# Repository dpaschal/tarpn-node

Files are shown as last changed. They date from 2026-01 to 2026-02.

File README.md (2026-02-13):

> **Important:** This isn't the documentation or code that Tadd KA2DEW supervises. That code is at https://tarpn.net/
> Technical support is available for the tarpn.net code and documentation at [tarpn@groups.io](https://groups.io/g/tarpn).

# TARPN Node

<p align="center">
  <a href="https://buymeacoffee.com/dpaschal">
    
  </a>
</p>

<p align="center">
  <b>☕ Buy me Claude Code credits or support a project! ☕</b>
</p>
<p align="center">
  <i>Every donation keeps the code flowing — these tools are built with your support.</i>
</p>

<p align="center">
  <a href="https://buymeacoffee.com/dpaschal">
    Buy Me A Coffee
  </a>
</p>

---

A modern, centralized repository for building TARPN (Terrestrial Amateur Radio Packet Network) nodes.




> **Note:** Documentation is actively being developed. Core scripts and STL files are ready for use. Some documentation pages contain placeholder content marked "Documentation In Progress".

## What is TARPN?

TARPN is an off-grid amateur radio social network that operates entirely over ham radio infrastructure - no internet required. It enables multi-state email, live chat, and social interaction using dedicated point-to-point VHF/UHF radio links.

**Key Features:**
- 100% ham operator controlled infrastructure
- Grid-independent (survives internet/cellular outages)
- Low cost (~$500-650 for complete dual-port node)
- Educational (teaches networking, radio, and digital communications)

## Quick Start

### Hardware Required

| Component | Qty | Est. Cost |
|---|-----|---|
| Raspberry Pi 4B (1GB+) | 1 | $45 |
| 16GB micro SD (Class 10) | 1 | $8 |
| NinoTNC N9600A | 2 | $80-140 |
| VHF/UHF Radio (surplus) | 2 | $100 |
| 13.8V Power Supply | 1 | $50-100 |
| Antennas | 2 | $140 |
| 3D Printed Enclosure | 1 | $20 |

See [hardware/bom/](hardware/bom/) for complete bill of materials with links.

### Software Installation

```bash
# Download and run the installer
curl -sSL https://raw.githubusercontent.com/dpaschal/tarpn-node/main/scripts/install.sh | bash
```

Or clone and run locally:

```bash
git clone https://github.com/dpaschal/tarpn-node.git
cd tarpn-node
./scripts/install.sh
```

### 3D Printed Enclosure

STL files for the single-wide nodebox are in [hardware/enclosure/stl/](hardware/enclosure/stl/).

**Print Settings:**
- Material: PLA or PETG
- Layer Height: 0.2mm
- Infill: 20-30%
- Supports: As needed per part

See [docs/hardware/enclosure/](docs/hardware/enclosure/) for assembly instructions.

## Documentation

Full documentation available at: **https://dpaschal.github.io/tarpn-node**

- [Hardware Build Guide](docs/hardware/)
- [Software Installation](docs/software/installation.md)
- [Configuration Guide](docs/software/configuration.md)
- [Network Setup](docs/network/)
- [Troubleshooting](docs/software/troubleshooting.md)

## Repository Structure

```
tarpn-node/
├── docs/               # MkDocs documentation
├── hardware/
│   ├── enclosure/stl/  # 3D print files
│   ├── wiring/         # Wiring diagrams
│   └── bom/            # Bill of materials
├── scripts/            # Installation and management scripts
├── config/             # Configuration templates
├── image/              # SD card image build system
└── tests/              # Automated tests
```

## TARPN Commands

After installation, use the `tarpn` command:

```bash
tarpn                  # Show status
tarpn config           # Configure node
tarpn service start    # Start background service
tarpn home start       # Start web interface
tarpn update           # Update TARPN software
tarpn backup           # Backup configuration
tarpn test             # Test node operation
```

## Community

- **NCPACKET (NC Area):** [ncpacket@groups.io](https://groups.io/g/ncpacket)
- **TARPN Technical:** [tarpn@groups.io](https://groups.io/g/tarpn)
- **Issues:** [GitHub Issues](https://github.com/dpaschal/tarpn-node/issues)

## Credits

- **TARPN Project:** Tadd Torborg (KA2DEW) - [tarpn.net](https://tarpn.net)
- **LinBPQ:** John Wiseman (G8BPQ) - [g8bpq/LinBPQ](https://github.com/g8bpq/LinBPQ)
- **NinoTNC:** Nino Carrillo (KK4HEJ)
- **Enclosure Design:** TARPN Community

## License

MIT License - See [LICENSE](LICENSE) for details.

---

*This repository modernizes and centralizes the TARPN node build process, previously scattered across multiple websites and scripts.*

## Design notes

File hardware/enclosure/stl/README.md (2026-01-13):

# Single-Wide Nodebox STL Files

3D printable enclosure for a TARPN node with dual radios and dual NinoTNCs.

**Design:** Tadd Torborg (KA2DEW)
**Version:** 2025-09-13

## Print Quantities

Based on the official assembly instructions, print the following quantities:

### Structural Components

| Qty | File | Description |
|-----|---|---|
| 16 | `beam-2025apr25-1.stl` | Horizontal beams |
| 16 | `corner-tower-T2025may01-1.stl` | Corner posts |
| 4 | `foot-jul15-1.stl` | Rubber foot mounts |

### Bottom Panels

| Qty | File | Description |
|-----|---|---|
| 4 | `bottom-panel-stephen-2024sep05-1.stl` | Bottom panels |
| 4 | `bottom-panel-key.stl` | Bottom panel locks |

### Side Panels

| Qty | File | Description |
|-----|---|---|
| 11 | `side-panel-jul09-1.stl` | Side panels |
| 1 | `right-half-with-vent-holes-25feb25-7.stl` | Vented right panel |
| 1 | `hinged-200mm-panel-2025may23-1.stl` | Hinged access panel |

### Roof Components

| Qty | File | Description |
|-----|---|---|
| 4 | `roof-corner-25jan03-1.stl` | Roof corner pieces |
| 4 | `roof-edge-beam-25jan04-2.stl` | Roof edge beams |
| 4 | `roof-quadrant-25jan05-1.stl` | Roof quadrant panels |

### NinoTNC Mounting

| Qty | File | Description |
|-----|---|---|
| 4 | `ninotnc-panel-jul15-2.stl` | TNC front panel |
| 4 | `ninotnc-tray-handle-2025apr28-2.stl` | TNC tray handle |
| 4 | `ninotnc-vertical-a4-tray-2025apr30-1.stl` | Vertical TNC tray |

### Power & Control

| Qty | File | Description |
|-----|---|---|
| 1 | `control-panel-25may27-2.stl` | Main control panel |
| 1 | `power-supply-panel-25feb01-1.stl` | Power supply panel |
| 1 | `power-supply-support-2025mar21-3.stl` | Power supply bracket |
| 1 | `fuse-holder-2025apr12-2.stl` | Fuse holder mount |
| 1 | `battery-jan02-1.stl` | Battery holder |

### I/O Cutouts

| Qty | File | Description |
|-----|---|---|
| 1 | `ethernet-socket-july30-1.stl` | Ethernet port cutout |
| 1 | `hdmi-and-usb-big-socket-hole-2025apr03-1.stl` | HDMI/USB cutout |
| 4 | `coax-hole-53mm-25jan02-1.stl` | Coax feedthrough (53mm) |
| 6 | `vented-53mm-jul16-1.stl` | Vented 53mm hole |

### Radio Mounts (Choose Based on Your Radios)

| Qty | File | Description |
|-----|---|---|
| 4 | `tait-radio-25jan03-1.stl` | Tait radio mount |
| as needed | `vertex_Mount_20250421-1.stl` | Vertex radio mount |
| as needed | `yeasu-ftm3100r-2025apr12-1.stl` | Yaesu FTM-3100R mount |

### Tools

| Qty | File | Description |
|-----|---|---|
| 1 | `nut-placer-in-beam-2025mar16-1.stl` | Tool for inserting nuts into beams |

### Multi-Part Files

| File | Description |
|---|---|
| `corners_and_beams.3mf` | Combined print of corners and beams |

## Print Settings

**Recommended:**

| Setting | Value |
|---|---|
| Material | PLA or PETG |
| Layer Height | 0.2mm |
| Infill | 20-30% |
| Walls | 3 perimeters |
| Top/Bottom | 4 layers |

**Per-Part Notes:**

- **Structural parts** (corners, beams): 30% infill for strength
- **Panels**: 20% infill is sufficient
- **Radio mounts**: PETG preferred for heat resistance near radios

## Hardware Required

- M3 x 10mm screws (qty: ~50)
- M3 x 35mm screws (qty: 4)
- M3 square nuts (qty: ~60)
- 2.5mm hex driver

## Total Print Summary

| Category | Part Count | Est. Print Time |
|---|---|---|
| Structural | 36 parts | ~20 hours |
| Panels | 16 parts | ~15 hours |
| Roof | 12 parts | ~8 hours |
| NinoTNC | 12 parts | ~6 hours |
| Power/Control | 5 parts | ~4 hours |
| I/O | 12 parts | ~3 hours |
| Radio Mounts | 4 parts | ~2 hours |
| **Total** | **~97 parts** | **~58 hours** |

*Print times estimated at 60mm/s with 0.2mm layer height*

## Assembly

See [Assembly Guide](../../../docs/hardware/enclosure/assembly.md) for detailed step-by-step instructions with photos.

## Credits

Enclosure designed by Tadd Torborg (KA2DEW) for the TARPN project.

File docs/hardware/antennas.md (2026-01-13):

# Antennas

!!! note "Documentation In Progress"
    This page is under construction. Check back soon!

## Antenna Types

| Type | Gain | Use Case |
|---|---|---|
| J-Pole | 0 dBd | Omnidirectional, local |
| Yagi | 6-12 dBd | Directional, long links |
| Collinear | 3-6 dBd | Omnidirectional, range |

## Recommendations

- **Point-to-point links**: Yagi antennas aimed at neighbor
- **Local coverage**: Vertical omnidirectional
- **Separate antennas** for each radio port

## Feedline

- Use quality coax (LMR-400 or equivalent)
- Keep runs as short as practical
- Use proper weatherproofing outdoors

## Resources

- [ARRL Antenna Book](http://www.arrl.org/antenna-book)

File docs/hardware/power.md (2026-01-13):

# Power Supply

!!! note "Documentation In Progress"
    This page is under construction. Check back soon!

## Requirements

| Component | Voltage | Current |
|---|---|---|
| Raspberry Pi | 5V | 3A |
| Radios (each) | 13.8V | 5-10A TX |
| NinoTNC | 5V (USB) | 100mA |

## Recommended Setup

- **Main supply**: 13.8V DC, 20-30A switching supply
- **Pi power**: USB-C 5V 3A adapter, or 12V-to-5V converter
- **Backup**: Optional 12V battery for Pi continuity

## Fusing

- Fuse each radio individually
- Main supply fuse at distribution point
- See [Fuse Holder STL](enclosure/stl/README.md)

## Resources

- [TARPN Power Guide](https://tarpn.net/t/builder/builders_power.html)

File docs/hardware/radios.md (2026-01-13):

# Radio Setup

!!! note "Documentation In Progress"
    This page is under construction. Check back soon!

## Recommended Radios

| Radio | Band | Notes |
|---|---|---|
| Tait TM8100/8200 | VHF/UHF | Excellent, surplus available |
| Motorola CDM1250 | VHF/UHF | Common, reliable |
| Yaesu FTM-3100R | 2m | New, affordable |
| Vertex VX-2200 | VHF/UHF | Commercial grade |

## Requirements

- FM transceiver (VHF or UHF)
- 9600 baud capable (for high-speed links)
- Flat audio response preferred
- 25-50W output typical

## Wiring

Connect radio to NinoTNC via audio cable:

- TX Audio (TNC to radio mic input)
- RX Audio (radio speaker to TNC)
- PTT (active low)
- Ground

## Resources

- [NinoTNC Connections](ninotnc.md#connections)
- [TARPN Radio Guide](https://tarpn.net/t/builder/builders_radio_selection.html)

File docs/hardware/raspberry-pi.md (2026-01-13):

# Raspberry Pi Setup

!!! note "Documentation In Progress"
    This page is under construction. Check back soon!

## Recommended Models

| Model | RAM | Status |
|---|-----|---|
| Pi 4B | 2GB+ | Recommended |
| Pi 3B+ | 1GB | Supported |
| Pi Zero 2 W | 512MB | Supported (limited) |

## OS Requirements

- Raspberry Pi OS (Bullseye or Bookworm)
- 32-bit or 64-bit supported

## Initial Setup

1. Flash Raspberry Pi OS to SD card
2. Enable SSH
3. Boot and connect to network
4. Run TARPN installer:

```bash
curl -sSL https://raw.githubusercontent.com/dpaschal/tarpn-node/main/scripts/install.sh | bash
```

## Resources

- [Raspberry Pi Imager](https://www.raspberrypi.com/software/)
- [TARPN Installation Guide](../software/installation.md)

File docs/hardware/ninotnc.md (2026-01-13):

# NinoTNC N9600A

The NinoTNC N9600A is the recommended TNC (Terminal Node Controller) for TARPN nodes. Designed by Nino Carrillo (KK4HEJ), it's a multi-mode USB KISS TNC supporting amateur packet radio from 300 to 19,200 baud.

**Designer:** Nino Carrillo, KK4HEJ

**In Service:** Over 2,800 boards shipped, 120+ units in NC Packet network

## Specifications

| Specification | Value |
|---|---|
| Interface | USB serial at 57,600 baud |
| Protocol | KISS |
| Layer 2 | AX.25, IL2P, IL2P+CRC |
| Baud Rates | 300, 1200, 2400, 3600, 4800, 9600, 19200 |
| RX Input | 0.3V - 3V peak-to-peak |
| Connectors | 9-pin DE9 (kit) or 6-pin mini-DIN (SMT) |
| Power | USB powered (5V) |

## Operating Modes

The NinoTNC supports 16 modes via the MODE switch, covering three protocol families:

### Legacy AX.25 Modes

| Mode | Baud | Modulation | Use Case |
|---|---|---|---|
| 300 AFSK | 300 | 1600/1800 Hz tones | SSB HF packet |
| 1200 AFSK | 1200 | Bell 202 | FM packet, APRS |
| 9600 GFSK | 9600 | G3RUH | High-speed FM |

### IL2P FEC Modes (Recommended)

| Mode | Baud | Modulation | Use Case |
|---|---|---|---|
| 300-600 BPSK/QPSK | 300-600 | PSK, 500 Hz BW | SSB HF |
| 1200-2400 BPSK/QPSK | 1200-2400 | PSK, 2400 Hz BW | FM/SSB |
| 3600 QPSK | 3600 | QPSK | FM (narrow filters OK) |
| 4800-19200 GFSK/C4FSK | 4800-19200 | G3RUH/FSK | Data port |

### Performance

| Mode | Throughput | Notes |
|---|---|---|
| 9600 G3RUH | 125 bytes/sec | With fast-switching radio |
| 2400 DPSK | Good | Works with mic-audio radios |
| 4800 GFSK | Good | For radios that can't do 9600 |

!!! info "IL2P Advantage"
    IL2P provides approximately **4dB improvement** in signal-to-noise ratio compared to AX.25.

## IL2P Protocol

The NinoTNC supports IL2P (Improved Layer 2 Protocol), which provides:

- **Forward Error Correction (FEC)** - Approximately 4dB improvement over standard AX.25
- **Better noise immunity** - More reliable links in marginal conditions
- **Backward compatible framing** - Works with existing AX.25 infrastructure
- **Designed by KK4HEJ** - Specifically for amateur radio packet

!!! tip "Use IL2P"
    IL2P is strongly recommended for TARPN links. It provides significant performance improvement with no hardware changes.

## Connections

### Audio Connections

The NinoTNC uses a 6-pin mini-DIN connector for radio audio:

| Pin | Signal | Description |
|-----|---|---|
| 1 | TX Audio | Transmit audio to radio |
| 2 | Ground | Audio ground |
| 3 | PTT | Push-to-talk (ground to transmit) |
| 4 | RX Audio | Receive audio from radio |
| 5 | Ground | Audio ground |
| 6 | +5V | Optional power output |

### USB Connection

Connect to any USB port on the Raspberry Pi. The NinoTNC appears as `/dev/ttyUSB0`, `/dev/ttyUSB1`, etc.

## Configuration

### Checking USB Connection

```bash
# List USB devices
tarpn usb

# Or manually
ls -la /dev/ttyUSB*
```

### Identifying TNCs

```bash
# Query TNC version
tarpn identify
```

### LinBPQ Port Configuration

In `bpq32.cfg`, configure a NinoTNC port:

```
PORT
  PORTNUM=1
  ID=VHF 9600 IL2P
  TYPE=ASYNC
  PROTOCOL=KISS
  COMPORT=/dev/ttyUSB0
  SPEED=57600
  CHANNEL=A
  PERSIST=128
  SLOTTIME=100
  TXDELAY=200
  TXTAIL=50
  QUALITY=203
  MAXFRAME=4
  FRACK=5000
  RESPTIME=1500
  RETRIES=5
  PACLEN=236
ENDPORT
```

## LED Indicators

The NinoTNC has five status LEDs:

| LED | Color | Designator | Function |
|-----|---|---|---|
| CRC | Red | D5 | CRC errors, high RX volume warning |
| Queue | Blue | D6 | TX queue has data waiting |
| RX | Green | D4 | Successful packet received (2 sec) |
| DCD | Yellow | D3 | Data Carrier Detect active |
| PTT | Red | D1 | Transmitting |

**Startup Sequence:** Four-LED sweep pattern indicates reset or mode change.

**CRC LED Tuning:** Adjust receive volume until CRC LED flickers, then reduce until it stops - this is optimal receive level.

## Firmware Updates

### Check Current Version

```bash
tarpn identify
```

### Flash New Firmware

1. Download firmware from TARPN website
2. Place `.hex` file in `/usr/local/etc/ninotnc/versions/`
3. Run firmware flash utility:

```bash
tarpn flash
```

Or manually with Python:

```bash
python3 flashtnc.py /dev/ttyUSB0 firmware.hex
```

## Troubleshooting

### TNC Not Detected

1. Check USB cable connection
2. Verify with `dmesg | tail` after plugging in
3. Check permissions: `ls -la /dev/ttyUSB*`
4. Add user to dialout group: `sudo usermod -a -G dialout pi`

### No TX/RX Activity

1. Verify audio cable connections
2. Check radio squelch settings
3. Verify PTT line is working
4. Check baud rate matches neighbor

### Poor Link Quality

1. Try adjusting TX delay (`TXDELAY` in config)
2. Verify audio levels (not too hot or too quiet)
3. Check antenna and feedline
4. Consider switching to IL2P if using AX.25

## Hardware Versions

| Version | Period | Status |
|---|---|---|
| A0, A1 | Aug 2018 - Jan 2020 | Unsupported |
| A2 | Jan 2020 - Aug 2020 | Supported (200 units) |
| A3 | May 2020 - Nov 2020 | Supported (800 units) |
| A4 | Dec 2020 - present | Current (thousands) |
| A4r3 | Feb 2024+ | Current production |

The A4r3 revision was created when the original MOSFET (Q1) was discontinued.

## Purchasing

### Kit Version (DIY)

- **PCB + CPU from ETSY:** ~$12 USD
- **Components from Mouser:** ~$30 USD
- **Total:** Under $40

### Assembled Units

- **RPC-Electronics:** ~$70 + shipping (SMT version)
- **HamServe.UK:** PCB, kits, or assembled (international)
- **OARC.UK via Tindie:** PCB + CPU (EU)

## Firmware

| CPU Type | Firmware Version |
|---|---|
| dsPIC33EP256 | v3.44 (current) |
| dsPIC33EP512 | v4.44 (current) |

!!! warning "Firmware Compatibility"
    Use v3.X firmware for EP256GP CPU, v4.X for EP512GP CPU. Do not mix versions.

## KISS Parameters for LinBPQ

```
SPEED=57600
PROTOCOL=KISS
PERSIST=225
SLOTTIME=20
FRACK=6000    ; 1200 baud
FRACK=2000    ; 9600 baud
PACLEN=236    ; 1200 baud
PACLEN=202    ; 9600 baud
```

## Resources

- [Operator's Manual](https://tarpn.net/t/nino-tnc/n9600a/n9600a_operation.html)
- [Info & Ordering](https://tarpn.net/t/nino-tnc/n9600a/n9600a_info.html)
- [Assembly Instructions](https://tarpn.net/t/nino-tnc/n9600a/n9600a3/n9600a3-assembly.html)
- [Firmware Updater (GitHub)](https://github.com/ninocarrillo/flashtnc)
- [IL2P Protocol Documentation](https://tarpn.net/t/builder/builders_tarpn_protocols.html)

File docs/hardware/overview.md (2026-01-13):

# Hardware Overview

A TARPN node consists of several key components working together to provide packet radio connectivity.

## Architecture

```
┌─────────────────────────────────────────────────────────┐
│                    TARPN Node                           │
├─────────────────────────────────────────────────────────┤
│                                                         │
│  ┌──────────┐    ┌──────────┐    ┌──────────────────┐  │
│  │ Antenna  │◄──►│  Radio   │◄──►│    NinoTNC       │  │
│  │  (VHF)   │    │   #1     │    │      #1          │  │
│  └──────────┘    └──────────┘    └────────┬─────────┘  │
│                                           │ USB        │
│  ┌──────────┐    ┌──────────┐    ┌───────▼──────────┐  │
│  │ Antenna  │◄──►│  Radio   │◄──►│    NinoTNC       │  │
│  │  (UHF)   │    │   #2     │    │      #2          │  │
│  └──────────┘    └──────────┘    └────────┬─────────┘  │
│                                           │ USB        │
│  ┌────────────────────────────────────────▼─────────┐  │
│  │              Raspberry Pi                         │  │
│  │  ┌─────────────────────────────────────────────┐ │  │
│  │  │           LinBPQ (G8BPQ Node)               │ │  │
│  │  │  • Packet Routing     • Web Interface       │ │  │
│  │  │  • BBS Mail System    • Chat Server         │ │  │
│  │  └─────────────────────────────────────────────┘ │  │
│  └──────────────────────────────────────────────────┘  │
│                                                         │
│  ┌──────────────────────────────────────────────────┐  │
│  │              13.8V Power Supply                   │  │
│  └──────────────────────────────────────────────────┘  │
└─────────────────────────────────────────────────────────┘
```

## Components

### Raspberry Pi

The brain of the node. Runs LinBPQ software for packet switching.

- **Recommended:** Raspberry Pi 4B (1GB+ RAM)
- **Also supported:** Pi 3B, 3B+, Zero 2W
- **OS:** Raspberry Pi OS (Bullseye or Bookworm)

### NinoTNC

Terminal Node Controller - converts digital data to/from radio signals.

- **Model:** N9600A (current version)
- **Interface:** USB (appears as /dev/ttyUSB*)
- **Protocols:** AX.25, IL2P (with FEC)
- **Speeds:** 300 - 19200 baud

### Radios

VHF/UHF FM transceivers for the RF links.

- **Recommended:** Surplus commercial land-mobile radios
- **Power:** 25-50W typical
- **Bands:** 2m (144 MHz), 70cm (440 MHz), 6m (50 MHz)

### Power Supply

- **Main:** 13.8V DC supply for radios (20A+ recommended)
- **Pi:** USB-C 5.1V 3A (can use 12V-5V converter)
- **Backup:** Optional GelCel battery for Pi

### Enclosure

Houses all components in a single portable unit.

- **3D Printed:** STL files provided
- **Wooden:** Traditional cabinet build
- **Commercial:** Various rack-mount options

## Typical Configurations

### Single Port (Starter)

- 1x Raspberry Pi
- 1x NinoTNC
- 1x Radio
- 1x Antenna

**Cost:** ~$200-300

### Dual Port (Standard)

- 1x Raspberry Pi
- 2x NinoTNC
- 2x Radio
- 2x Antenna

**Cost:** ~$500-650

### Multi-Port (Advanced)

- 1x Raspberry Pi
- 3-4x NinoTNC
- 3-4x Radio
- Multiple antennas

**Cost:** ~$800+

## Next Steps

1. [Shopping List](shopping-list.md) - Complete parts list with links
2. [Raspberry Pi Setup](raspberry-pi.md) - Choosing and preparing the Pi
3. [NinoTNC](ninotnc.md) - TNC assembly and configuration
4. [Radios](radios.md) - Radio selection and wiring

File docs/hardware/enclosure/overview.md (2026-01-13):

# Enclosure Overview

!!! note "Documentation In Progress"
    This page is under construction. Check back soon!

## 3D Printed Nodebox

The official TARPN enclosure designed by Tadd Torborg (KA2DEW).

**Features:**

- Modular snap-fit design
- Holds 4 radios and 4 NinoTNCs
- Integrated ventilation
- Tool-free panel removal

## Components

- 97 total printed parts
- ~58 hours print time
- PLA or PETG material

## Documentation

- [STL Files & Print Quantities](stl/README.md)
- [Assembly Guide](assembly.md)
- [Hardware (Fasteners)](../../hardware/bom/mcmaster-carr.md)

## Alternative Enclosures

- Rack-mount chassis
- Ammo can (weatherproof)
- Pelican case (portable)

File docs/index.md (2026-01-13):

> **Important:** This isn't the documentation or code that Tadd KA2DEW supervises. That code is at https://tarpn.net/
> Technical support is available for the tarpn.net code and documentation at [tarpn@groups.io](https://groups.io/g/tarpn).

# TARPN Node Documentation

Welcome to the TARPN Node documentation. This guide will help you build and configure a complete TARPN (Terrestrial Amateur Radio Packet Network) node.

## What is TARPN?

TARPN is an **off-grid amateur radio social network** that operates entirely over ham radio infrastructure. No internet required - by design.

**Key Features:**

- Multi-state email, chat, and social interaction
- Dedicated point-to-point VHF/UHF radio links
- 100% ham operator controlled
- Grid-independent (survives internet/cellular outages)
- Low cost barrier (~$500-650 for complete node)

## Quick Start

### 1. Gather Hardware

You'll need:

- Raspberry Pi 4B (1GB+ RAM)
- 2x NinoTNC N9600A
- 2x VHF/UHF radios (surplus commercial recommended)
- Power supply, antennas, cables
- 3D printed or wooden enclosure

See the [Shopping List](hardware/shopping-list.md) for complete details.

### 2. Build the Enclosure

Download and print the STL files from `hardware/enclosure/stl/`, or build a traditional wooden cabinet.

See the [Enclosure Guide](hardware/enclosure/overview.md) for assembly instructions.

### 3. Install Software

```bash
# On your Raspberry Pi
curl -sSL https://raw.githubusercontent.com/dpaschal/tarpn-node/main/scripts/install.sh | bash
```

See [Installation Guide](software/installation.md) for detailed steps.

### 4. Configure Your Node

```bash
tarpn config
```

See [Configuration Guide](software/configuration.md) for all options.

### 5. Join the Network

Coordinate with your local TARPN group to link your node to neighbors.

See [Network Linking](network/linking.md) for details.

## Documentation Sections

| Section | Description |
|---|---|
| [Hardware](hardware/overview.md) | Component selection, wiring, enclosure build |
| [Software](software/installation.md) | Installation, configuration, commands |
| [Network](network/architecture.md) | How TARPN works, frequencies, linking |
| [Advanced](advanced/building-from-source.md) | Building from source, custom images |

## Community

- **NCPACKET (NC Area):** [ncpacket@groups.io](https://groups.io/g/ncpacket)
- **TARPN Technical:** [tarpn@groups.io](https://groups.io/g/tarpn)
- **GitHub Issues:** [Report bugs or request features](https://github.com/dpaschal/tarpn-node/issues)

## Credits

- **TARPN Project:** Tadd Torborg (KA2DEW)
- **LinBPQ:** John Wiseman (G8BPQ)
- **NinoTNC:** Nino Carrillo (KK4HEJ)

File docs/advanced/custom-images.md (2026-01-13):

# Custom SD Card Images

!!! note "Documentation In Progress"
    This page is under construction. Check back soon!

## Overview

Pre-built SD card images simplify TARPN deployment. This guide covers creating custom images.

## Tools

- [pi-gen](https://github.com/RPi-Distro/pi-gen) - Official Raspberry Pi image builder
- [Packer](https://www.packer.io/) - Automated image building

## Basic Process

1. Start with Raspberry Pi OS Lite
2. Run TARPN installer
3. Configure base settings
4. Shrink and compress image

## Automated Builds

GitHub Actions workflow for automated image builds coming soon.

## Resources

- [pi-gen Documentation](https://github.com/RPi-Distro/pi-gen)
- [TARPN Installation](../software/installation.md)

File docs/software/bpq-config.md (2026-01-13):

# BPQ Configuration Reference

!!! note "Documentation In Progress"
    This page is under construction. Check back soon!

## Overview

LinBPQ uses `bpq32.cfg` as its main configuration file. This defines ports, routing, and services.

## Basic Structure

```
; Node identity
NODECALL=N0CALL-2
NODEALIAS=MYNODE
LOCATOR=EM95

; Port definitions
PORT
  PORTNUM=1
  ID=VHF 9600
  TYPE=ASYNC
  PROTOCOL=KISS
  COMPORT=/dev/ttyUSB0
  SPEED=57600
ENDPORT

; Applications
APPLICATION 1,BBS,,N0CALL-1,BBS,256
APPLICATION 2,CHAT,,N0CALL-3,CHAT,256
```

## Port Parameters

| Parameter | Description |
|---|---|
| PORTNUM | Port number (1-32) |
| COMPORT | Serial device path |
| SPEED | Serial baud rate (57600 for NinoTNC) |
| PERSIST | CSMA persistence (225 typical) |
| SLOTTIME | Slot time in ms (20 typical) |
| TXDELAY | TX delay in ms |

## Resources

- [Example Config](https://github.com/dpaschal/tarpn-node/blob/main/config/examples/dual-port.cfg)
- [G8BPQ Documentation](https://www.cantab.net/users/john.wiseman/Documents/)

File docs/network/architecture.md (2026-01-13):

# Network Architecture

TARPN uses a mesh network topology where each node connects to multiple neighbors via dedicated point-to-point radio links.

## Network Topology

```
        ┌───────┐           ┌───────┐
        │Node A │───────────│Node B │
        └───┬───┘           └───┬───┘
            │                   │
            │     ┌───────┐     │
            └─────│Node C │─────┘
                  └───┬───┘
                      │
                  ┌───┴───┐
                  │Node D │
                  └───────┘
```

Each link is a dedicated simplex (one frequency) or half-duplex connection between exactly two nodes.

## Protocol Stack

| Layer | Protocol | Description |
|---|---|---|
| Application | BBS, Chat, Telnet | User services |
| Session | NET/ROM | Node routing and session management |
| Transport | AX.25 / IL2P | Packet framing, FEC |
| Physical | FM Radio | VHF/UHF modulation |

## Routing

TARPN nodes use NET/ROM (Network Routing) protocol implemented by LinBPQ:

- **Automatic route discovery** - Nodes broadcast routing tables
- **Quality-based routing** - Links scored by reliability
- **Multi-hop forwarding** - Packets routed through network
- **Alias addressing** - Human-readable node names

## Link Types

### Point-to-Point Radio Links

The primary link type. Each radio port connects to exactly one neighbor.

```
[Node A Radio 1] ──── frequency 1 ────> [Node B Radio 2]
                <──── frequency 1 ─────
```

Configuration:

- Simplex frequency per link
- 9600 baud recommended (1200 baud minimum)
- IL2P protocol for FEC

### AXIP/AXUDP Links (Internet)

Connect distant nodes over the Internet:

```
[Node A] ──── Internet ────> [Node B]
```

!!! warning "Not Recommended"
    Internet links bypass the amateur radio purpose of TARPN. Use sparingly for critical backbone connections only.

## Node Types

### Full Node

- 2-4 radio ports
- Part of the mesh backbone
- Routes traffic for other nodes

### Leaf Node

- 1-2 radio ports
- Connects to the network but doesn't route
- End-user access point

### Gateway Node

- Provides Internet connectivity (email, etc.)
- Connects to external services
- Usually also a full node

## Quality Metrics

LinBPQ assigns quality scores to each link:

| Quality | Description |
|---|---|
| 255 | Perfect (direct connection) |
| 203 | Excellent radio link |
| 150 | Good radio link |
| 100 | Marginal link |
| < 100 | Poor link |

Quality is used for routing decisions - higher quality paths preferred.

## Traffic Flow

### Local Traffic

```
[User] ──> [Local Node] ──> [Application]
```

### Remote Traffic

```
[User] ──> [Node A] ──> [Node B] ──> [Node C] ──> [Application]
```

The network automatically routes packets through the optimal path.

## Services

### BBS (Bulletin Board System)

- Personal mailboxes
- Bulletin boards
- Message forwarding between nodes

### Chat

- Real-time keyboard-to-keyboard
- Group chat rooms
- Available via TARPN-HOME web interface

### Telnet

- Remote node access
- Command line interface
- Diagnostic tools

## Network Coordination

### NC Packet (North Carolina)

The original TARPN network, coordinated through ncpacket.net.

### Frequency Coordination

- Coordinate with neighbors to avoid interference
- See [Frequencies](frequencies.md) for allocation guide

### Linking Guidelines

- Only link to neighbors you can reliably reach
- Maintain links you commit to
- See [Network Rules](rules.md) for policies

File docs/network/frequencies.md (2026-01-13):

# Frequency Allocation

TARPN links operate on simplex frequencies in VHF and UHF amateur bands. Each link between two nodes uses a dedicated frequency.

## Frequency Bands

### 2 Meter (VHF) - 144-148 MHz

Primary band for most TARPN links due to good propagation and available surplus equipment.

| Frequency Range | Use |
|---|-----|
| 144.91 - 145.09 | Packet/data (weak signal adjacent) |
| 145.50 - 145.80 | Misc/experimental |
| 146.40 - 146.58 | Simplex |
| 147.42 - 147.57 | Simplex |

### 70 Centimeter (UHF) - 420-450 MHz

Good for shorter links with less interference.

| Frequency Range | Use |
|---|-----|
| 420.00 - 426.00 | Digital/packet modes |
| 430.00 - 432.00 | Digital/mixed |
| 440.00 - 445.00 | Shared simplex |
| 445.00 - 447.00 | Shared simplex |

### 1.25 Meter (222 MHz)

Less common but excellent for packet with minimal interference.

| Frequency Range | Use |
|---|-----|
| 222.10 - 223.38 | Weak signal/digital |
| 223.52 - 223.64 | Simplex digital |

## NC Packet Coordination

The NC Packet network (ncpacket.net) maintains a frequency coordination database. Check with your regional coordinator before selecting frequencies.

### Typical NC Packet Allocations

| Band | Common Frequencies |
|---|---|
| 2m | 145.01, 145.03, 145.05, 145.07, 145.09 |
| 70cm | 441.025, 441.050, 441.075, 445.925, 445.950 |

## Selecting a Frequency

### Guidelines

1. **Check coordination database** - See if frequency is already in use nearby
2. **Avoid repeater inputs/outputs** - Don't interfere with voice repeaters
3. **Use designated packet segments** - Prefer frequencies allocated for data
4. **Coordinate with neighbor** - Both nodes must use same frequency
5. **Consider propagation** - Higher frequencies = shorter range

### Frequency Separation

For multiple links at the same site:

| Band | Minimum Separation |
|---|---|
| 2m | 20 kHz between channels |
| 70cm | 25 kHz between channels |

### Example 4-Port Node

```
Port 1 (Link to Node A): 145.01 MHz
Port 2 (Link to Node B): 145.03 MHz
Port 3 (Link to Node C): 441.025 MHz
Port 4 (Link to Node D): 441.050 MHz
```

## Baud Rate vs Bandwidth

| Baud Rate | Bandwidth | Notes |
|---|---|---|
| 1200 | 12.5 kHz | Standard AFSK, most compatible |
| 9600 | 25 kHz | G3RUH FSK, recommended |
| 19200 | 25 kHz | High speed G3RUH |

!!! tip "9600 Baud Recommended"
    Use 9600 baud for best throughput while maintaining reliable links. 1200 baud only if distance requires it.

## Programming Your Radio

Most radios need to be programmed with:

- **Receive frequency** - Same as transmit for simplex
- **Transmit frequency** - Same as receive for simplex
- **Squelch** - Set to open or carrier squelch
- **Power** - Usually low/medium (5-25W)
- **CTCSS/DCS** - Not used (disable)
- **Narrow/Wide** - Wide for 9600 baud

## Avoiding Interference

### Don't Use

- Repeater input/output pairs
- Calling frequencies (146.52, 446.00, etc.)
- Satellite frequencies
- Emergency/ARES frequencies
- Active simplex channels in your area

### Monitoring

Before going live:

```bash
# Listen for activity on your planned frequency
tarpn listen 1
```

## Frequency Plan Template

| Port | Direction | Frequency | Band | Baud | Neighbor |
|---|---|---|---|---|---|
| 1 | East | 145.01 | 2m | 9600 | N0CALL-2 |
| 2 | West | 145.03 | 2m | 9600 | K0ABC-2 |
| 3 | North | 441.025 | 70cm | 9600 | W0XYZ-2 |
| 4 | South | 441.050 | 70cm | 9600 | K0QRS-2 |

## Coordination Resources

- **NC Packet**: [ncpacket.net](https://ncpacket.net) - Southeastern US coordination
- **TARPN**: [tarpn.net](https://tarpn.net) - General TARPN information
- **ARRL Band Plan**: [arrl.org/band-plan](https://www.arrl.org/band-plan) - Official band plans

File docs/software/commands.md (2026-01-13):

# TARPN Command Reference

The `tarpn` command provides management functions for your TARPN node.

## Status Commands

### `tarpn`

Show current node status (default when no command given).

```bash
$ tarpn
TARPN Node Status
━━━━━━━━━━━━━━━━━━━━━━━━━━━━━━━━━━━━━━━━
BPQ Node: RUNNING
  PID: 1234
  Uptime: 2:15:30

Network:
  IP Address: 192.168.1.100
  Web Interface: http://192.168.1.100:8080

USB Devices:
  /dev/ttyUSB0
  /dev/ttyUSB1
```

### `tarpn info`

Display detailed system information.

```bash
tarpn info
```

Shows CPU, memory, disk, and temperature information.

## Service Management

### `tarpn service start`

Start the TARPN node as a background service.

```bash
tarpn service start
```

### `tarpn service stop`

Stop the background service.

```bash
tarpn service stop
```

### `tarpn service restart`

Restart the service (useful after configuration changes).

```bash
tarpn service restart
```

### `tarpn service status`

Show systemd service status.

```bash
tarpn service status
```

## Configuration

### `tarpn config`

Launch interactive configuration wizard.

```bash
tarpn config
```

!!! warning
    Stop the node before running config: `tarpn service stop`

### `tarpn test`

Run node interactively for testing. Output goes to terminal.

```bash
tarpn test
```

Press `Ctrl+C` to stop.

## Maintenance

### `tarpn update`

Update TARPN software from GitHub.

```bash
tarpn update
```

!!! note
    Restart the service after updating: `tarpn service restart`

### `tarpn backup`

Create a backup of node configuration.

```bash
tarpn backup
```

Backups are saved to `/opt/tarpn/backups/`.

### `tarpn restore`

Restore configuration from a backup.

```bash
tarpn restore
```

## Monitoring

### `tarpn log`

View live node logs.

```bash
tarpn log
```

Press `Ctrl+C` to stop watching.

### `tarpn shell`

Open a telnet session to the BPQ command interface.

```bash
tarpn shell
```

### `tarpn listen <port>`

Monitor packets on a specific port.

```bash
tarpn listen 1
```

### `tarpn linktest <port>`

Test link quality by sending test packets.

```bash
tarpn linktest 1
```

## System

### `tarpn shutdown`

Safely shutdown the node and Raspberry Pi.

```bash
tarpn shutdown
```

!!! warning
    This will power off the Pi. You'll need physical access to restart.

### `tarpn reboot`

Safely reboot the node.

```bash
tarpn reboot
```

## Examples

### Starting Fresh

```bash
# Stop any running instance
tarpn service stop

# Configure the node
tarpn config

# Test interactively
tarpn test

# If test looks good, start as service
tarpn service start
```

### Daily Operations

```bash
# Check status
tarpn

# View logs if something seems wrong
tarpn log

# Update software
tarpn update
tarpn service restart
```

### Before Maintenance

```bash
# Backup configuration
tarpn backup

# Safely shutdown
tarpn shutdown
```

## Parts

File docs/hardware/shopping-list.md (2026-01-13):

# Shopping List

!!! note "Documentation In Progress"
    This page is under construction. Check back soon!

## Quick Summary

For a complete 4-port TARPN node, you'll need:

- 1x Raspberry Pi 4B (2GB+)
- 4x NinoTNC N9600A
- 4x VHF/UHF Radio (Tait, Motorola, or Yaesu)
- 1x 13.8V Power Supply (20A+)
- 4x Antennas
- Hardware fasteners (see [McMaster-Carr list](../hardware/bom/mcmaster-carr.md))

## Detailed Lists

- [Bill of Materials](../hardware/bom/bom.md)
- [McMaster-Carr Hardware](../hardware/bom/mcmaster-carr.md)
- [STL Files for 3D Printing](enclosure/stl/README.md)

## External Resources

- [TARPN Shopping List](https://tarpn.net/t/builder/builders_node_shopping_list.html)
- [NinoTNC Ordering](https://tarpn.net/t/nino-tnc/n9600a/n9600a_info.html)

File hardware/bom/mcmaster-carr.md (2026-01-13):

# McMaster-Carr Hardware List

Official hardware list from Tadd Torborg (KA2DEW) for assembling a 4-port TARPN node box.

**Source:** McMaster-Carr requisition dated April 12, 2025

## Fasteners

| Item | Description | Part # | Qty | Pack Size | Price | Total |
|---|---|---|-----|---|---|---|
| 1 | Brass Hex Nut, M2.5 x 0.45mm Thread | [90690A035](https://www.mcmaster.com/90690A035) | 1 | 100 ea | $8.61 | $8.61 |
| 2 | Flanged Socket Head Screw, M4 x 0.7mm, 10mm Long | [92235A108](https://www.mcmaster.com/92235A108) | 1 | 50 ea | $15.31 | $15.31 |
| 3 | Medium-Strength Steel Thin-Profile Square Nuts, Zinc-Plated, M3 x 0.5mm | [97259A101](https://www.mcmaster.com/97259A101) | 2 | 100 ea | $8.00 | $16.00 |
| 4 | 18-8 Stainless Steel Socket Head Screw, M3 x 0.50mm, 65mm Long | [91292A315](https://www.mcmaster.com/91292A315) | 2 | 25 ea | $12.14 | $24.28 |
| 5 | Alloy Steel Socket Head Screw, Black-Oxide, M3 x 0.5mm, 40mm Long | [91290A136](https://www.mcmaster.com/91290A136) | 1 | 25 ea | $4.75 | $4.75 |
| 6 | Alloy Steel Socket Head Screw, Zinc Plated, M3 x 0.5mm, 10mm Long | [95263A134](https://www.mcmaster.com/95263A134) | 4 | 50 ea | $8.55 | $34.20 |
| 7 | Alloy Steel Socket Head Screw, Black, M2.5 x 0.45mm, 14mm Long | [91290A053](https://www.mcmaster.com/91290A053) | 1 | 50 ea | $7.52 | $7.52 |

## Tools

| Item | Description | Part # | Qty | Price | Total |
|---|---|---|-----|---|---|
| 8 | Ultra-Grip Screwdriver, 3mm Hex | [57585A55](https://www.mcmaster.com/57585A55) | 1 | $6.58 | $6.58 |
| 9 | Ultra-Grip Screwdriver, 2mm Hex | [57585A53](https://www.mcmaster.com/57585A53) | 1 | $5.46 | $5.46 |
| 10 | Ultra-Grip Screwdriver, 2.5mm Hex | [57585A54](https://www.mcmaster.com/57585A54) | 1 | $6.14 | $6.14 |
| 11 | Ball-End Hex Bit, 1/4" Hex Shank, 2.5mm Hex Size | [5492A82](https://www.mcmaster.com/5492A82) | 1 | $2.65 | $2.65 |

## Order Summary

| Category | Total |
|---|---|
| Fasteners | $110.67 |
| Tools | $20.83 |
| **Merchandise Total** | **$131.50** |

## What You Get

After this order, you'll have:

- **100x** M2.5 brass hex nuts
- **50x** M4 x 10mm flanged socket head screws
- **200x** M3 thin-profile square nuts (the key fastener for the enclosure)
- **50x** M3 x 65mm stainless socket head screws
- **25x** M3 x 40mm black socket head screws
- **200x** M3 x 10mm zinc socket head screws
- **50x** M2.5 x 14mm black socket head screws
- **3x** Hex screwdrivers (2mm, 2.5mm, 3mm)
- **1x** Ball-end hex bit for power tools

## Notes

- The M3 square nuts (97259A101) are the most critical - you need ~60 per enclosure
- Two packs of 100 gives you enough for one enclosure with plenty of spares
- The 10mm M3 screws are used most frequently - 4 packs recommended
- Tools are one-time purchase

## Alternative Sources

These parts can also be sourced from:

- **Amazon** - Search by size (e.g., "M3 x 10mm socket head screw")
- **Bolt Depot** - [boltdepot.com](https://www.boltdepot.com)
- **Fastenal** - [fastenal.com](https://www.fastenal.com)
- **Home Depot/Lowes** - Limited metric selection but available

## Order Link

Original McMaster-Carr order (may be expired):
```
https://www.mcmaster.com/order/rcvRtedOrd.aspx?ordid=6642819776971
```

Or order parts individually at [mcmaster.com](https://www.mcmaster.com)

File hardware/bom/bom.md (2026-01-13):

# Bill of Materials - TARPN Node (Dual Port)

Complete parts list for building a 2-radio, 2-TNC TARPN node.

## Electronics

| Component | Qty | Est. Cost | Source | Notes |
|---|-----|---|---|---|
| Raspberry Pi 4B (1GB+) | 1 | $45 | [RPi Foundation](https://www.raspberrypi.com/) | 2GB recommended |
| 16GB micro SD (Class 10) | 1 | $8 | Amazon | SanDisk recommended |
| USB-C Power Supply (5.1V 3A) | 1 | $15 | [Official RPi PSU](https://www.raspberrypi.com/products/type-c-power-supply/) | |
| NinoTNC N9600A | 2 | $40-70 ea | [TARPN](https://tarpn.net/t/nino-tnc/n9600a/n9600a_info.html) | Kit or assembled |

## Radios

| Component | Qty | Est. Cost | Source | Notes |
|---|-----|---|---|---|
| VHF/UHF Radio | 2 | $50 ea | eBay, hamfests | See recommended models below |
| TNC-Radio Cable (6-pin mini-DIN) | 2 | $10 ea | [TARPN](https://tarpn.net) | Match to radio model |
| USB A-B Cable (for NinoTNC) | 2 | $5 ea | Amazon | |

### Recommended Radios

**Kenwood (1200 baud):**
- TK-760/760H (VHF) - $30-50
- TK-860/860H (UHF) - $30-50
- TK-862G (UHF, 8ch) - $40-60

**Vertex (6m capable):**
- FTL-1011 (50 MHz) - $35-70
- FTL-2011 (VHF) - $35-70

**Tait (9600 baud capable):**
- TM8105 - $50-80

## Power

| Component | Qty | Est. Cost | Source | Notes |
|---|-----|---|---|---|
| 13.8V Power Supply (20A+) | 1 | $50-100 | Amazon, ham stores | MFJ-4230MV recommended |
| Anderson Powerpole Connectors | 10 | $15 | Powerwerx | |
| Fuse Block | 1 | $15 | Amazon | |
| 12V to 5V USB Converter | 1 | $10 | Amazon | For Pi power from 13.8V |
| GelCel Battery (optional) | 1 | $25 | Amazon | Backup power |

## Antennas

| Component | Qty | Est. Cost | Source | Notes |
|---|-----|---|---|---|
| VHF/UHF Antenna | 2 | $50-70 ea | Ham stores | Comet GP-3 recommended |
| Coax (RG-8X or LMR-240) | 50ft | $30 | DX Engineering | |
| PL-259 Connectors | 4 | $10 | Amazon | |
| Diplexer/Triplexer | 1 | $30 | Amazon | If sharing antenna |

## Enclosure

| Component | Qty | Est. Cost | Source | Notes |
|---|-----|---|---|---|
| 3D Printed Parts | 1 set | $20 | Self-printed | ~500g PLA/PETG |
| M3 x 8mm Screws | 50 | $8 | Amazon | |
| M3 Nuts | 30 | $5 | Amazon | |
| M3 Heat-Set Inserts | 20 | $10 | Amazon | Optional |
| Rubber Feet | 4 | $5 | Amazon | |

## Cables & Misc

| Component | Qty | Est. Cost | Source | Notes |
|---|-----|---|---|---|
| Ethernet Cable (Cat5e+) | 1 | $5 | Amazon | For initial setup |
| HDMI Cable | 1 | $5 | Amazon | For initial setup |
| USB Keyboard | 1 | - | - | For initial setup |
| Wire (14-16 AWG) | 10ft | $5 | Hardware store | Power distribution |
| Heat Shrink Tubing | 1 kit | $8 | Amazon | |

## Cost Summary

| Category | Cost Range |
|---|---|
| Electronics | $108-175 |
| Radios | $120-200 |
| Power | $90-150 |
| Antennas | $130-200 |
| Enclosure | $50 |
| Cables/Misc | $30 |
| **Total** | **$528-805** |

## Where to Buy

- **NinoTNC:** Request via [TARPN email list](https://groups.io/g/tarpn)
- **Radios:** eBay, local hamfests, [Ham Radio Outlet](https://www.hamradio.com/)
- **Power Supplies:** Amazon, [DX Engineering](https://www.dxengineering.com/)
- **Antennas:** [DX Engineering](https://www.dxengineering.com/), local ham stores
- **3D Printing:** Self-print or [JLCPCB](https://jlcpcb.com/3d-printing)

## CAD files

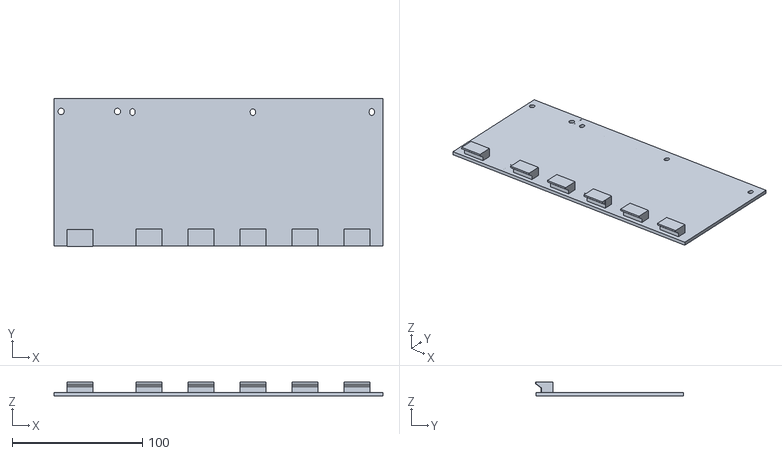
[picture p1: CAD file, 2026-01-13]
hardware/enclosure/stl/full-panel-jul10-2.stl
253.0 x 113.8 x 11.0

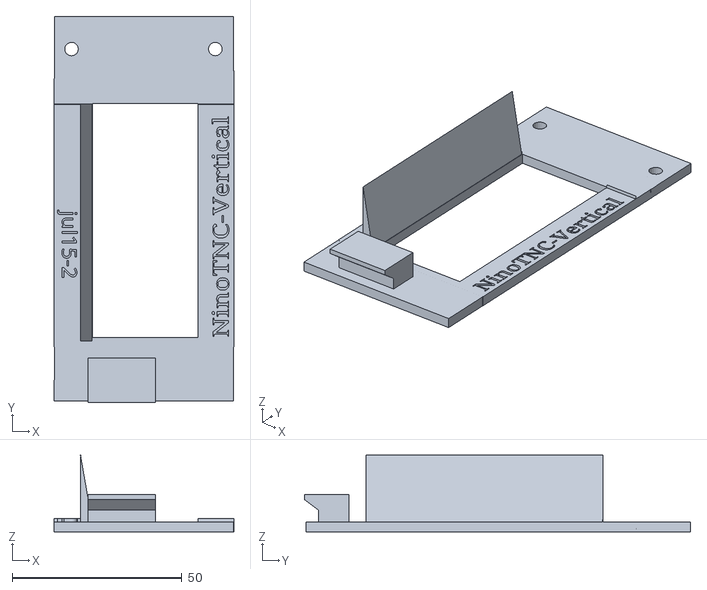
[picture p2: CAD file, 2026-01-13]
hardware/enclosure/stl/ninotnc-panel-jul15-2.stl
53.1 x 113.8 x 22.7

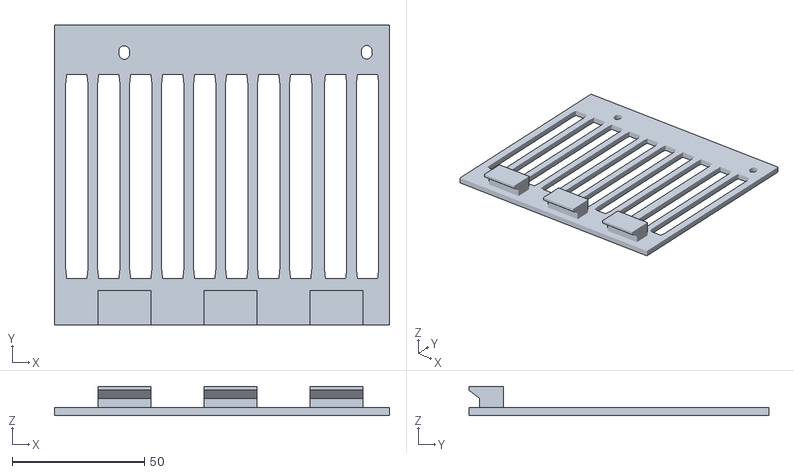
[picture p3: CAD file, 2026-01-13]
hardware/enclosure/stl/left-half-panel-jul12-2.stl
126.4 x 113.4 x 11.0

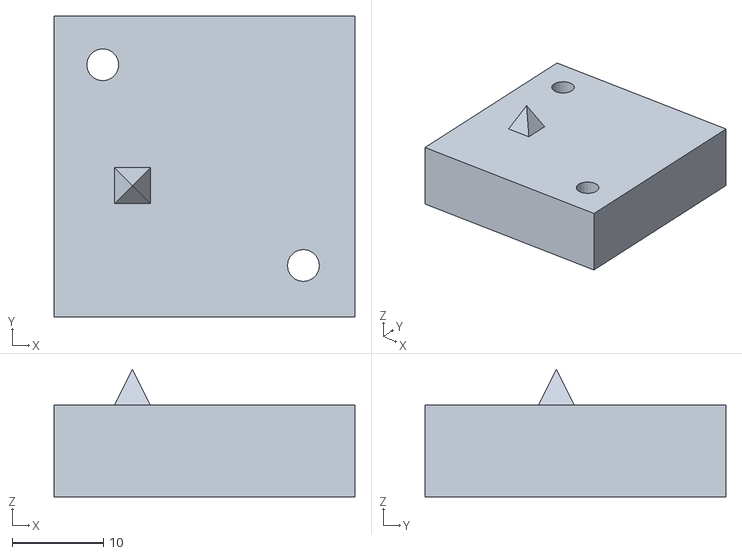
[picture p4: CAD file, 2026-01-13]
hardware/enclosure/stl/foot-jul15-1.stl
33.0 x 33.0 x 14.0

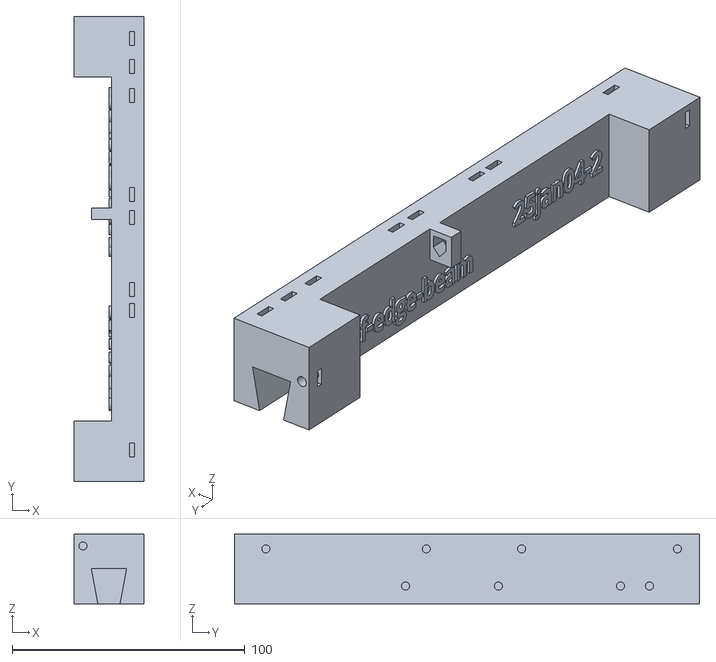
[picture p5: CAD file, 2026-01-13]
hardware/enclosure/stl/roof-edge-beam-25jan04-2.stl
30.0 x 200.0 x 30.0

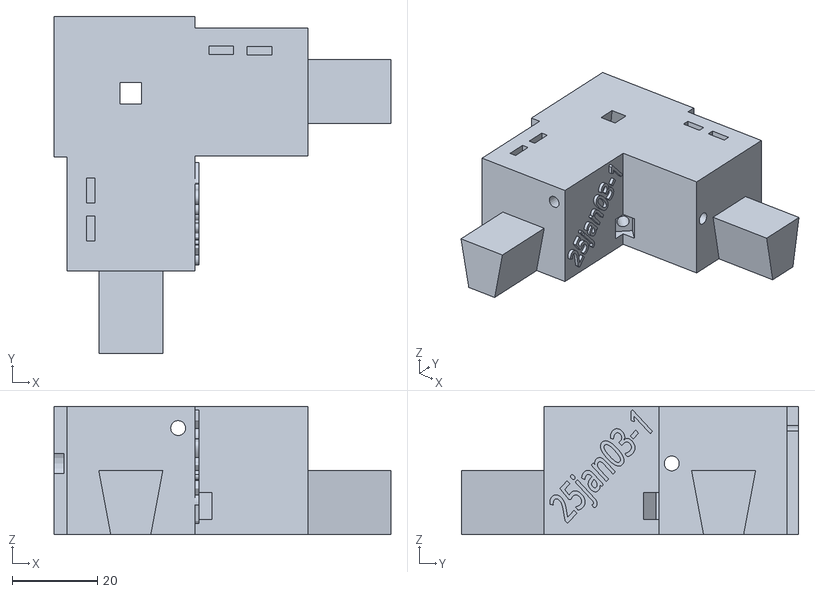
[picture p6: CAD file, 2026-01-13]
hardware/enclosure/stl/roof-corner-25jan03-1.stl
79.0 x 79.1 x 30.1

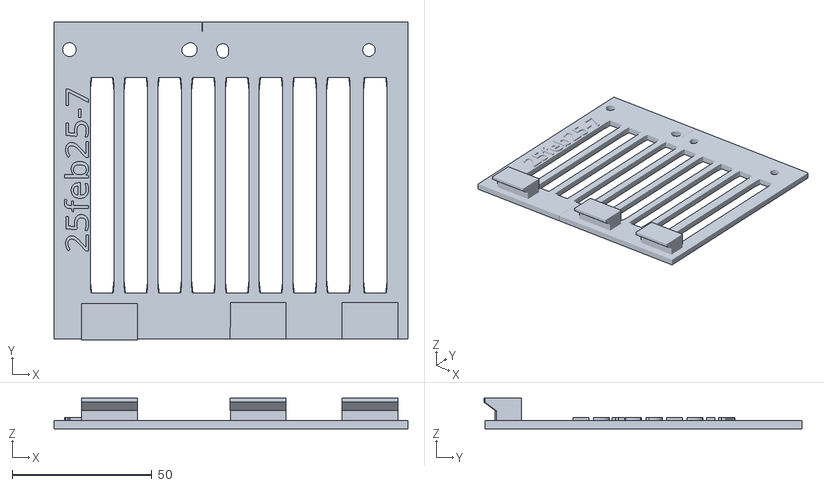
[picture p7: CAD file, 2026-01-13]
hardware/enclosure/stl/right-half-with-vent-holes-25feb25-7.stl
126.6 x 113.8 x 11.0

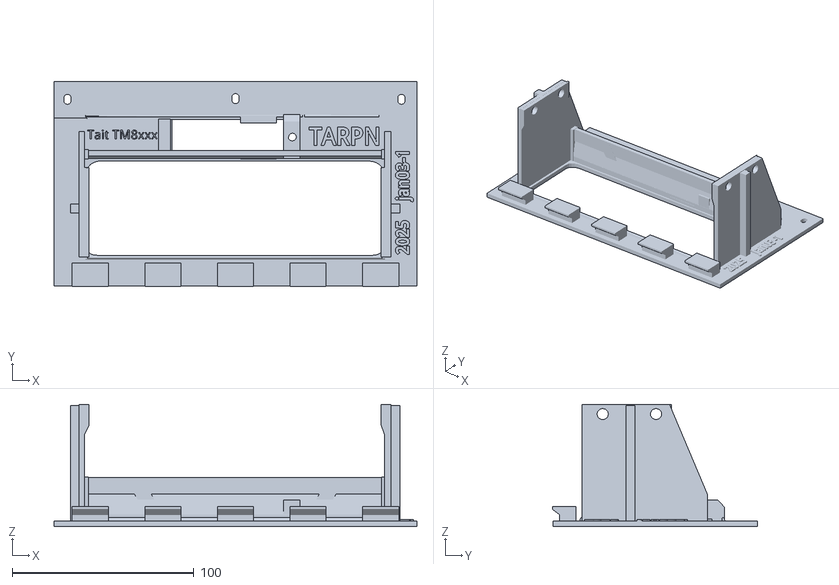
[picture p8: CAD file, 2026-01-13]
hardware/enclosure/stl/tait-radio-25jan03-1.stl
200.0 x 113.2 x 67.3

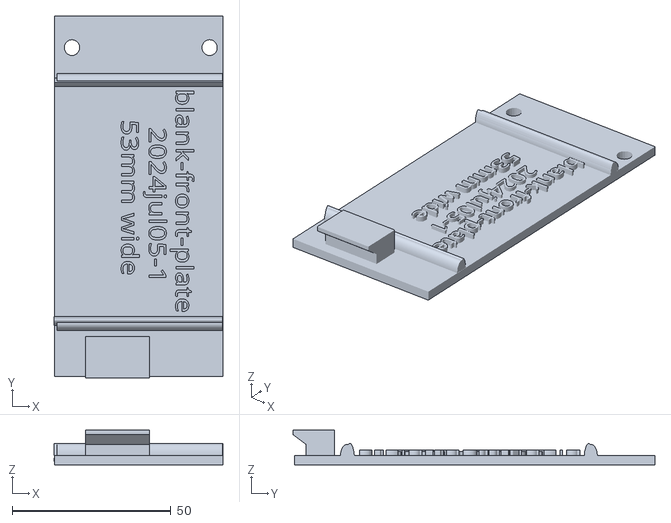
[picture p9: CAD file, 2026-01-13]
hardware/enclosure/stl/blank-right-hand-front-plate-2024jul05-1.stl
53.0 x 113.8 x 11.0

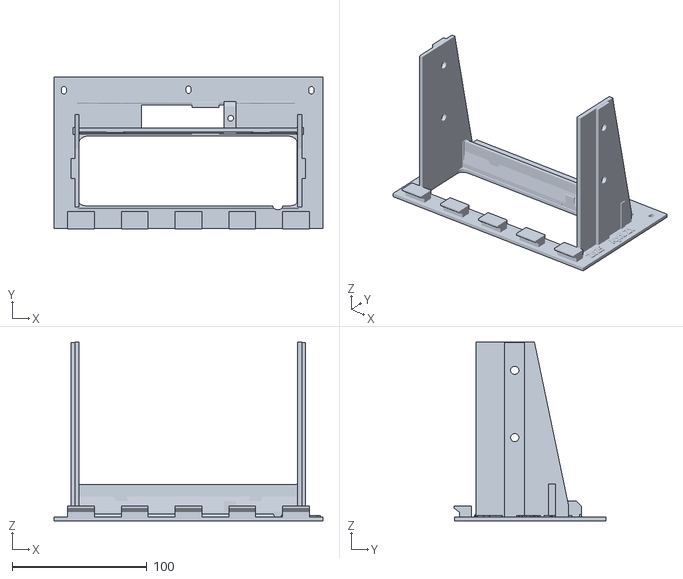
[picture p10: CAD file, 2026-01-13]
hardware/enclosure/stl/vertex_Mount_20250421-1.stl
200.0 x 113.2 x 133.0

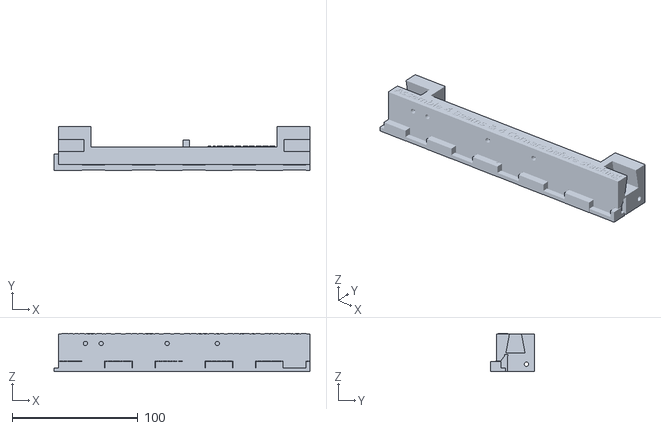
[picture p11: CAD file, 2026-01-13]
hardware/enclosure/stl/beam-2025apr25-1.stl
203.7 x 34.7 x 30.3

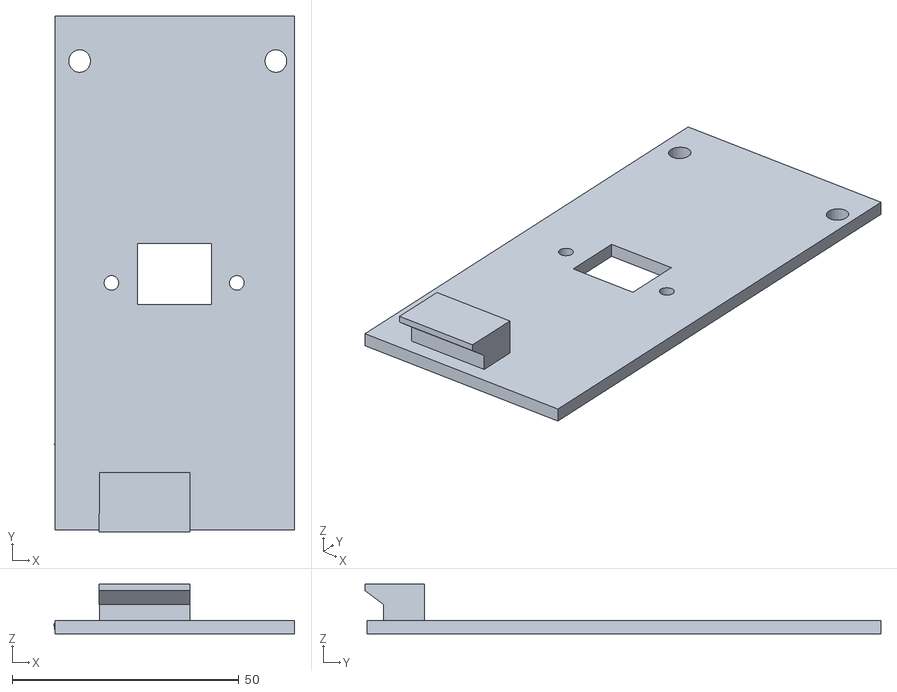
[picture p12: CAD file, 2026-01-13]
hardware/enclosure/stl/ethernet-socket-july30-1.stl
53.0 x 113.8 x 11.0

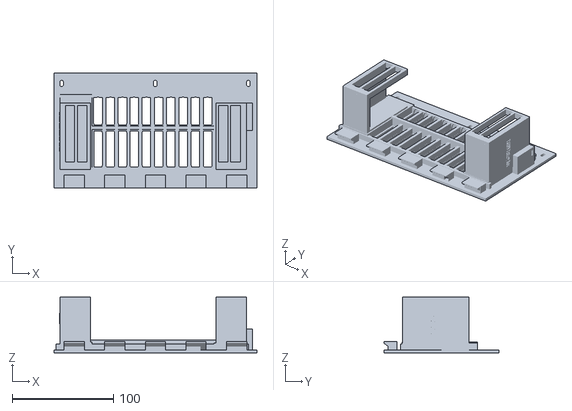
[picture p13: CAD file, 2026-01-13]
hardware/enclosure/stl/battery-jan02-1.stl
200.1 x 113.4 x 55.0

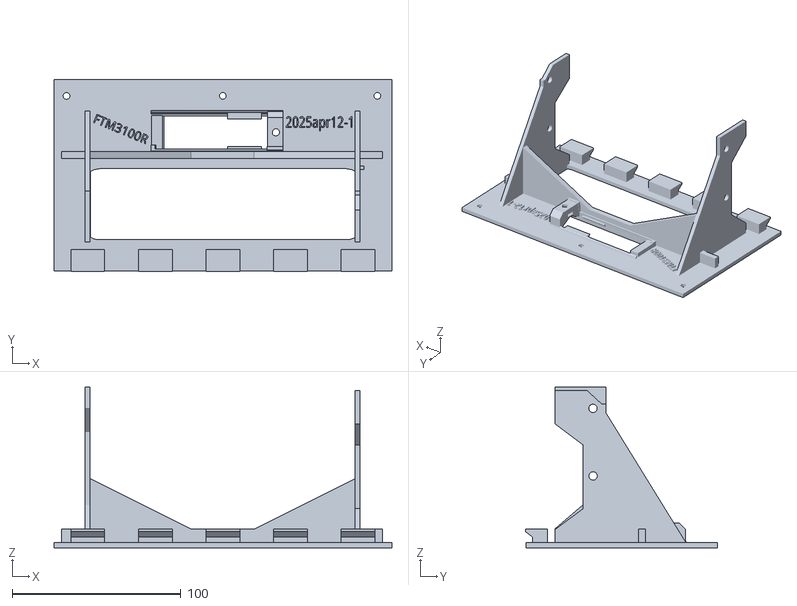
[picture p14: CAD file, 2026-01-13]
hardware/enclosure/stl/yeasu-ftm3100r-2025apr12-1.stl
200.1 x 113.8 x 95.0

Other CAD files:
hardware/enclosure/stl/vented-53mm-jul16-1.stl
hardware/enclosure/stl/hdmi-and-usb-big-socket-hole-2025apr03-1.stl
hardware/enclosure/stl/corners_and_beams.3mf
hardware/enclosure/stl/power-supply-panel-25feb01-1.stl
hardware/enclosure/stl/bottom-panel-key.stl
hardware/enclosure/stl/bottom-panel-stephen-2024sep05-1.stl
hardware/enclosure/stl/coax-hole-53mm-25jan02-1.stl
hardware/enclosure/stl/control-panel-25may27-2.stl
hardware/enclosure/stl/corner-tower-T2025may01-1.stl
hardware/enclosure/stl/fuse-holder-2025apr12-2.stl
hardware/enclosure/stl/hinged-200mm-panel-2025may23-1.stl
hardware/enclosure/stl/ninotnc-tray-handle-2025apr28-2.stl
hardware/enclosure/stl/ninotnc-vertical-a4-tray-2025apr30-1.stl
hardware/enclosure/stl/nut-placer-in-beam-2025mar16-1.stl
hardware/enclosure/stl/power-supply-support-2025mar21-3.stl
hardware/enclosure/stl/right-half-panel-aug01-2.stl
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

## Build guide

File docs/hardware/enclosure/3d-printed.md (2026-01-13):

# 3D Printed Enclosure Build

The official TARPN nodebox enclosure designed by Tadd Torborg (KA2DEW).

## Overview

A modular, snap-fit enclosure that houses:

- Raspberry Pi
- 4x NinoTNC
- 4x VHF/UHF radios
- Power supply and distribution
- Control panel with LEDs and switches

## Print Requirements

| Specification | Value |
|---|---|
| Total Parts | ~97 |
| Print Time | ~58 hours |
| Material | PLA or PETG |
| Layer Height | 0.2mm |
| Infill | 20-30% |

## STL Files

All STL files are included in this repository:

**[View STL File List & Print Quantities](stl/README.md)**

### Key Components

| Category | Parts |
|---|---|
| Structural (corners, beams) | 36 |
| Panels | 16 |
| Roof | 12 |
| NinoTNC mounts | 12 |
| Power/Control | 5 |
| I/O cutouts | 12 |
| Radio mounts | 4 |

## Hardware Required

From [McMaster-Carr](../../hardware/bom/mcmaster-carr.md):

- M3 x 10mm socket head screws (~200)
- M3 thin-profile square nuts (~60 per enclosure)
- M3 x 35mm screws (4)
- M3 x 65mm screws (for corner towers)
- M2.5 screws and nuts (for TNC mounting)

**Total hardware cost:** ~$130

## Print Settings

### Structural Parts (corners, beams)

```
Infill: 30%
Walls: 3 perimeters
Material: PLA or PETG
```

### Panels

```
Infill: 20%
Walls: 3 perimeters
Material: PLA
```

### Radio Mounts

```
Infill: 30%
Material: PETG (heat resistance)
```

## Assembly

See the **[Assembly Guide](assembly.md)** for step-by-step instructions.

## Tips

- Print corners and beams together using the `.3mf` file
- Use the nut placer tool for inserting square nuts
- Don't fully tighten screws until all parts are positioned
- PETG recommended for parts near radios (heat)

## Credits

Enclosure designed by **Tadd Torborg (KA2DEW)** for the TARPN project.

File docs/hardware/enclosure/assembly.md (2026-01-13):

# Enclosure Assembly Guide

Step-by-step instructions for assembling the single-wide nodebox enclosure.

## Parts List (Print Quantities)

| Qty | File | Description |
|-----|---|---|
| 1 | `nut-placer-in-beam-2025mar16-1.stl` | Assembly tool |
| 16 | `beam-2025apr25-1.stl` | Horizontal beams |
| 16 | `corner-tower-T2025may01-1.stl` | Corner posts |
| 4 | `bottom-panel-key.stl` | Bottom panel locks |
| 4 | `bottom-panel-stephen-2024sep05-1.stl` | Bottom panels |
| 4 | `foot-jul15-1.stl` | Rubber foot mounts |
| 1 | `battery-jan02-1.stl` | Battery holder |
| 4 | `coax-hole-53mm-25jan02-1.stl` | Coax feedthrough |
| 1 | `hinged-200mm-panel-2025may23-1.stl` | Hinged access panel |
| 4 | `ninotnc-tray-handle-2025apr28-2.stl` | TNC tray handles |
| 4 | `ninotnc-vertical-a4-tray-2025apr30-1.stl` | Vertical TNC trays |
| 1 | `control-panel-25may27-2.stl` | Main control panel |
| 1 | `ethernet-socket-july30-1.stl` | Ethernet port cutout |
| 1 | `fuse-holder-2025apr12-2.stl` | Fuse holder mount |
| 1 | `hdmi-and-usb-big-socket-hole-2025apr03-1.stl` | HDMI/USB cutout |
| 1 | `power-supply-panel-25feb01-1.stl` | Power supply panel |
| 1 | `power-supply-support-2025mar21-3.stl` | Power supply bracket |
| 1 | `right-half-with-vent-holes-25feb25-7.stl` | Vented right panel |
| 4 | `roof-corner-25jan03-1.stl` | Roof corner pieces |
| 4 | `roof-edge-beam-25jan04-2.stl` | Roof edge beams |
| 4 | `roof-quadrant-25jan05-1.stl` | Roof quadrant panels |
| 11 | `side-panel-jul09-1.stl` | Side panels |
| 4 | `ninotnc-panel-jul15-2.stl` | TNC front panels |
| 6 | `vented-53mm-jul16-1.stl` | Vented 53mm holes |

### Radio Mounts (Choose Based on Your Radios)

| Qty | File | Description |
|-----|---|---|
| 4 | `tait-radio-25jan03-1.stl` | Tait radio mount |
| - | `vertex_Mount_20250421-1.stl` | Vertex radio mount |
| - | `yeasu-ftm3100r-2025apr12-1.stl` | Yaesu FTM-3100R mount |

## Hardware Required

- M3 x 10mm screws (qty: ~50)
- M3 x 35mm screws (qty: 4)
- M3 square nuts (qty: ~60)
- M3 round lugs (qty: as needed)
- 2.5mm hex driver

## Assembly Instructions

### Step 1: Bottom Panel Assembly

1. Obtain 4 bottom-panel-keys and 4 bottom-panels
2. Assemble them into a square with the edges and corner posts facing up
3. Obtain the foot objects
4. Insert square nuts, 2 per foot
5. Use two M3 10mm screws in each bottom-panel to attach the foot
6. Repeat for all 4 bottom-panels

### Step 2: Corner Tower and Beam Assembly

1. Obtain 4 beams and 4 corner-towers
2. Assemble two corner-towers on either side of a single beam such that the hook slots of each corner tower blends into the hook slots at the end of the beam
3. Orient the 3 parts with the two towers up and the beam setting on the table
4. Insert M3 square nuts into the two slots which are facing up on the corner towers where they connect to the beam
5. Obtain a 10mm long M3 screw and insert it into the beam on the inside of the two ends to intersect with the inserted M3 square nut
6. Tighten the two 10mm M3 screws using a 2.5mm driver
7. Make another assembly with two corner towers and one beam - including screwing the 3 parts together
8. Obtain two more beams and attach them (and screw them) into the two previously unused connector-legs on the corner towers of one of the assemblies
9. Attach the 2nd corner-tower/beam/corner-tower to the open ends of the two beams

### Step 3: Join Frame to Base

1. Lay the 4 beams + 4 corner-towers assembly on the bottom-panels and snap them together
2. Observe the beam/tower assembly and note that there are seven hook positions on each side of the four-sided structure
3. If you look into each hook receiver, you will see there are slots for M3 square nuts
4. There are two nut-slots in the hooks at each tower and four more in the hook receivers on each beam

### Step 4: Install Square Nuts

1. Slide the nuts into the slots and force them to line up on the screw hole through the face of the beam and tower by using the nut placer tool
2. **Tip:** Tilting the entire structure left (30 degrees or so) and right can give you a nice slot to slide the nuts in
3. Two of the slots are in unfortunate positions where canting can't help - use the supplied placement tool to aid installation of M3 square nuts in those slots
4. Repeat this process for all four corner towers and all four beams
5. Install 10mm screws in 24 locations through the bottom quadrant panels and into the corner-towers and beams

### Step 5: Corner Tower Long Screws

1. Place a square nut in the inside/back of the corner tower
2. Use a 35mm screw partially screwed into the nut to force the nut into position on the back (inside view) of the corner tower
3. Unscrew the 35mm screw and then insert that screw into the outside view of the tower and thread it in
4. As the 35mm screw reaches the captive square nut, hold the square nut into place with a finger and slowly screw the 35mm into the nut
5. Remove your finger and then tighten the 35mm into the screw
6. Repeat for the other 3 corners

### Step 6: Control Panel PCB Assembly

1. Assemble the Control Panel PCB with:
   - LEDs
   - Pushbuttons
   - Slide switch
   - Battery lugs (on back)
   - 2x5 header (on back)

### Step 7: Control Panel Installation

1. Obtain the Control Panel pieces (control panel back-shield and boost-regulator platform)
2. Using four slide-in nuts and four 10mm screws, install the control panel
3. Using two slide-in nuts and two 10mm screws, install the control panel shield

### Step 8: Boost Regulator

1. Obtain the Boost regulator and boost regulator platform
2. Using four 2.5mm screws and nuts, mount the Boost regulator to the platform

### Step 9: Power Wiring

**Wire preparation:**

- 2x 6" pieces of black/white wire (16-20 gauge) - strip and tin one end 1/4"
- 1x 18" piece of black/white wire (16-20 gauge)
- 1x 14" piece of red/black zip-cord wire (16-20 gauge)

!!! note
    The 18" and 14" lengths provide extra room. Cut them to fit before attaching a lug to the other end - do that later, after the box assembly is started.

1. Split the red and black for 2"
2. Attach four Negative wires to a single round-lug
3. Screw the round-lug to a hole in the Control Panel platform
4. The lug will be on the 'top' of the platform along with the Boost regulator

**Wire destinations from the negative lug:**
- Negative terminal on the battery
- Negative bus on the fuse box
- Both ends of the Boost regulator

!!! tip
    Strip the two short negative wires to the Boost regulator about 1/4 inch and tin with solder before attaching to the Boost Regulator screw terminals.

### Step 10: Continue Assembly

*Additional steps for radio mounting, NinoTNC installation, and roof assembly to be added.*

---

## Tips

- Keep M3 square nuts organized - you'll need many of them
- The nut placer tool is essential for difficult-to-reach slots
- Tilting the frame helps nuts slide into position
- Don't fully tighten screws until all parts are in place
- Test fit components before final assembly

## Next Steps

After completing the enclosure:

1. [Mount the Raspberry Pi](../raspberry-pi.md)
2. [Install NinoTNCs](../ninotnc.md)
3. [Wire the radios](../radios.md)
4. [Connect power](../power.md)

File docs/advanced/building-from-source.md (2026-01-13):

# Building from Source

!!! note "Documentation In Progress"
    This page is under construction. Check back soon!

## LinBPQ

LinBPQ source is available from G8BPQ:

```bash
git clone https://github.com/g8bpq/LinBPQ.git
cd LinBPQ
make
```

### Dependencies

```bash
sudo apt-get install build-essential libpcap-dev libasound2-dev
```

## NinoTNC Firmware

Firmware source and tools:

- [flashtnc (GitHub)](https://github.com/ninocarrillo/flashtnc)

## Resources

- [G8BPQ LinBPQ Source](https://github.com/g8bpq/LinBPQ)
- [LinBPQ RTG Distribution](https://github.com/pe1rrr/linbpq_rtg)

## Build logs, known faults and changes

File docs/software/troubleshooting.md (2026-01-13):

# Troubleshooting

!!! note "Documentation In Progress"
    This page is under construction. Check back soon!

## Common Issues

### Node Won't Start

```bash
# Check status
tarpn

# View logs
tarpn log

# Test interactively
tarpn test
```

### TNC Not Detected

```bash
# List USB devices
tarpn usb

# Check permissions
ls -la /dev/ttyUSB*

# Add user to dialout group
sudo usermod -a -G dialout pi
```

### No RF Activity

1. Check antenna connections
2. Verify radio programming
3. Check PTT line with `tarpn identify`
4. Monitor with `tarpn listen 1`

### Poor Link Quality

1. Check signal levels
2. Adjust TX deviation
3. Verify baud rate matches neighbor
4. Consider switching to IL2P

## Getting Help

- [TARPN Mailing List](https://tarpn.net)
- [NC Packet Forums](https://ncpacket.net)
- [GitHub Issues](https://github.com/dpaschal/tarpn-node/issues)

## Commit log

2026-01-13 Initial commit: TARPN node modernization
    - 32 STL files for single-wide nodebox enclosure
    - Modern install.sh and tarpn management command
    - MkDocs documentation structure
    - Bill of materials with pricing
    - Example dual-port BPQ configuration
    - GitHub Actions for docs deployment
    [battery-jan02-1.stl, beam-2025apr25-1.stl, blank-right-hand-front-plate-2024jul05-1.stl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]
2026-01-13 Add assembly instructions and McMaster-Carr hardware list
    - docs/hardware/enclosure/assembly.md: Step-by-step enclosure assembly guide
    from Tadd Torborg's official instructions
    - hardware/bom/mcmaster-carr.md: Official McMaster-Carr parts list with
    part numbers, quantities, and pricing ($131.50 total)
    - hardware/enclosure/stl/README.md: Updated with corrected part counts
2026-01-13 Add NinoTNC documentation and enhance scripts
    NinoTNC Documentation (from KK4HEJ specs):
    - docs/hardware/ninotnc.md: Complete guide with specs, modes, LEDs,
    firmware versions, purchasing options, KISS parameters
    - Sources: tarpn.net operator's manual, info pages
    Network Documentation:
    - docs/network/architecture.md: Mesh topology, protocol stack, routing
    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
2026-01-13 Add documentation stub pages for all nav items
    Created placeholder pages with basic structure for:
    - Hardware: shopping-list, raspberry-pi, radios, antennas, power
    - Enclosure: overview, 3d-printed build guide
    - Network: linking, rules
    - Software: configuration, bpq-config, troubleshooting
    - Advanced: building-from-source, custom-images, contributing
    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
2026-02-13 Add donation blurb to README
    Every donation keeps the code flowing — these tools are built with your support.
